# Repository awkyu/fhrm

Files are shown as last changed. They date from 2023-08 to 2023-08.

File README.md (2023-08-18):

# fhrm
BME 398: Fetal Heart Rate Monitor Circuit Design

This project was a small design project that was never fully realized as a proposal for an at-home Fetal Heart Rate Monitor. Signal artefacts are a major issue in current fetal heart rate sensors, leading to misdiagnoses that can lead to fetal mortality. Both Fetal Heart Rate and Fetal Movement are essential indicators for fetal health, providing information on cardiovascular and nervous system development, respectively. The device proposed here aims to limit these artefacts.

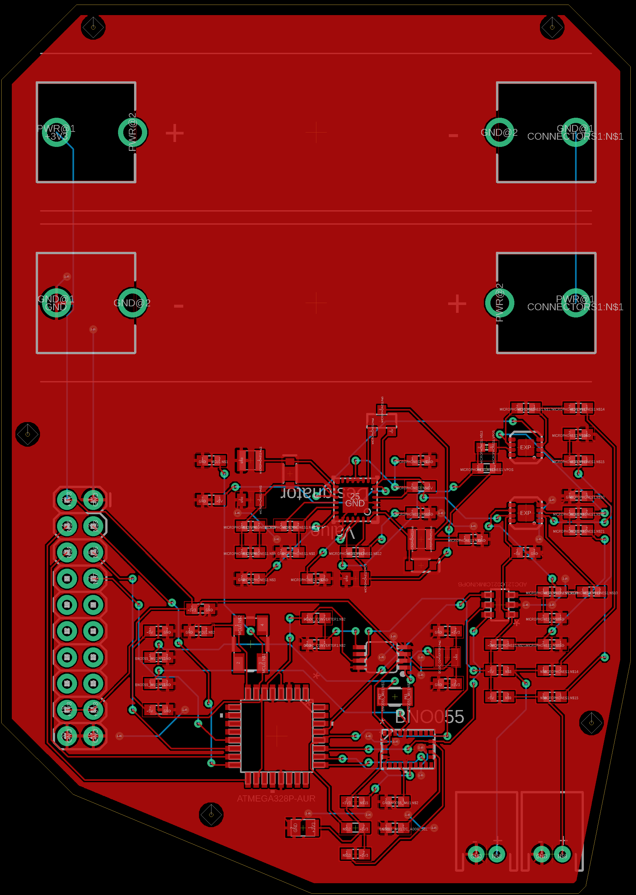
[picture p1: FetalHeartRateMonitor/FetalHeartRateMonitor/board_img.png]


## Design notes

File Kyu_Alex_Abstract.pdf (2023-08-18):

Abstract— Signal artefacts are a major issue in current fetal heart rate sensors, leading to misdiagnoses that can lead to fetal mortality. Both Fetal Heart Rate and Fetal Movement are essential indicators for fetal health, providing information on cardiovascular and nervous system development, respectively. The device proposed here aims to limit these artefacts.

Clinical Relevance— The design presented establishes an alternative device that would eliminate Maternal Heart Rate Artefact in Fetal Heart Rate measurements while providing additional movement information, reducing misinterpretation of signal output and misdiagnosis of abnormal fetal heart rates.

I. INTRODUCTION

In the perinatal period of pregnancy, both Fetal Heart Rate and Fetal Movement are major health indicators. Fetal movement has been shown to identify an infants’ neuro-motor development and brain dysfunction while Fetal Heart Rate indicative to fetal conditions that could lead to pre-existing fetal death [1, 2].

Currently, fetal heart rate is captured through cardiotocography, a method that uses ultrasound waves. When an abnormal heart rate is detected, a physician may decide to deliver the fetus early by performing a cesarean section. However, two artefacts may appear in these which could lead to a misdiagnosis. The first is the Maternal Heart Rate Artefact (MHRA) when the mother’s heart rate is misinterpreted by the CTG machine as the fetus’s and the second is the Fetal Heart Rate Artefact (FHRA) when a fetal heart rate is processed or outputted incorrectly—this can occur in the case of twins where one fetus’s heart rate can be interpreted as the others. A preliminary study identified these artefacts as part of 40% of perinatal fatalities examined in a sample report from 2009 to 2019 [1]. The device here provides a proposed way to measure fetal heart rate more accurately by eliminating these artefacts to decrease rates of perinatal mortality while also providing other fetal movement characteristics.

II. METHODS
The proposed sensor presented here is a dual microphone transducer to capture fetal heart rate with an IMU sensor to capture fetal movement. One microphone would be used to capture the heart rate of the fetus while the other microphone would be used to filter out ambient sounds and the maternal heart rate, using a differential operational amplifier topology. This would eliminate or reduce MHRA. This signal was then converted into a digital signal using a non-inverting level shifter. The IMU would be used to capture fetal movements, like other accelerometer-based fetal movement sensor systems. This system also includes a touchscreen for user interaction and to display relevant information related to the sensor readings.

III. RESULTS
The dual microphone schematic is shown below.

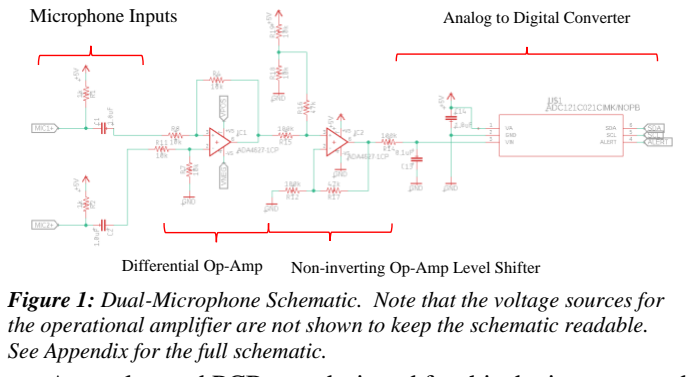
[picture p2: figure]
See Appendix for the full schematic.; Microphone Inputs; Differential Op-Amp; Analog to Digital Converter; Non-inverting Op-Amp Level Shifter

A two-layered PCB was designed for this device, powered by two AA batteries. All circuit components are on the top layer, except the ports that connect to the touchscreen which are on the bottom side. This eliminates the problem of the touchscreen inadvertently interacting with other components on the PCB. See Appendix for a figure of the PCB.

IV. DISCUSSION & CONCLUSION
It is worth noting that this is more of a proof of concept for a potential solution to some common problems that can occur with currently used cardiotocography devices while also providing additional fetal health informatics. However, additional filters, and methods should be investigated to
improve measurements. | For example, reinvestigating
ultrasound | transducers, | additional | microphones, | and
additional filtering methods may help further eliminate noise for fetal heart rate monitoring. And for fetal movement monitoring, other vibration-based sensors should be investigated like piezoelectric diaphragms and other acoustic sensors. These other sensors have been shown to be able to detect weaker movements, but also tend to generate higher power signal artefacts [2, 3].

Furthermore, board design should be analyzed to make sure that it is optimized for both noise reduction and for overall product design. Port placement, touchscreen placement, and battery placement should be reconsidered from a product perspective. Finally, other components should be analyzed to ensure that analog and digital signals are in their respective sections.

A. Kyu

## Proposed Wearable Fetal Heart Rate and Fetal Movement Sensor that Eliminates Maternal Heart Rate Artefact

Figure 1: Dual-Microphone Schematic. Note that the voltage sources for the operational amplifier are not shown to keep the schematic readable.

REFERENCES

[1] D. J. Kiely, L. W. Oppenheimer, and J. C. Dornan, “Unrecognized maternal heart rate artefact in cases of perinatal mortality reported to the United States Food and Drug Administration from 2009 to 2019: a critical patient safety issue,” BMC Pregnancy and Childbirth, vol. 19, no. 1, Dec. 2019, doi: 10.1186/s12884-019-2660-5.
[2] J. Lai et al., “Performance of a wearable acoustic system for fetal movement discrimination,” PLOS ONE, vol. 13, no. 5, p. e0195728, May 2018, doi: 10.1371/journal.pone.0195728.
[3] A. K. Ghosh et al., “A Novel Fetal Movement Simulator for the Performance Evaluation of Vibration Sensors for Wearable Fetal Movement Monitors,” Sensors, vol 20, no. 21, p. 6020, Oct 2020, doi:10.3390/s20216020

## Appendix

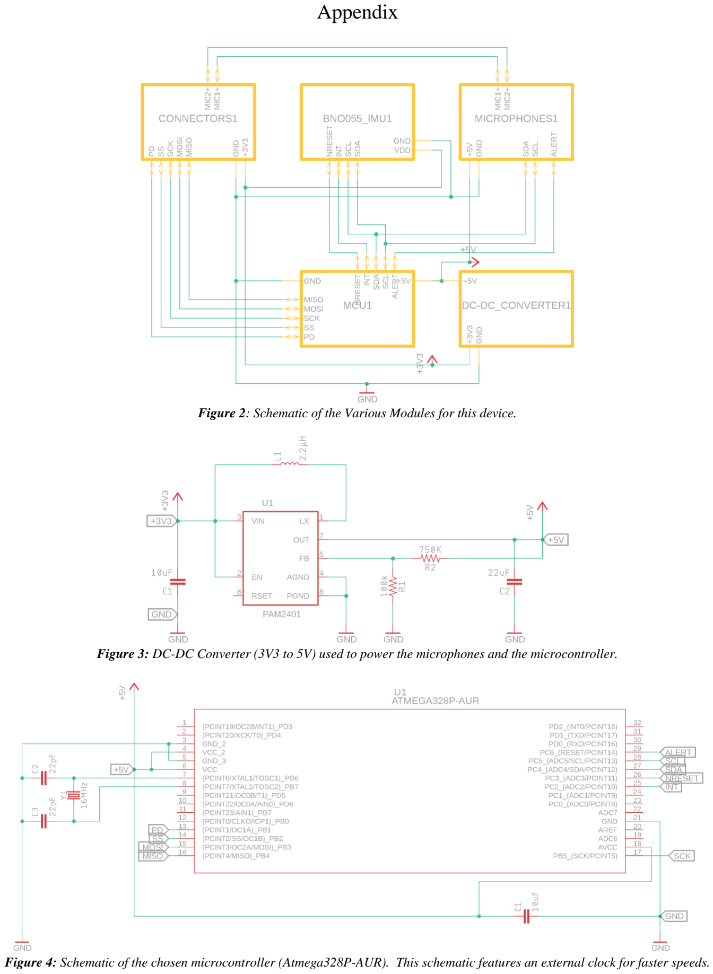
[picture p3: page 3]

Figure 2: Schematic of the Various Modules for this device.

Figure 3: DC-DC Converter (3V3 to 5V) used to power the microphones and the microcontroller.

Figure 4: Schematic of the chosen microcontroller (Atmega328P-AUR). This schematic features an external clock for faster speeds.

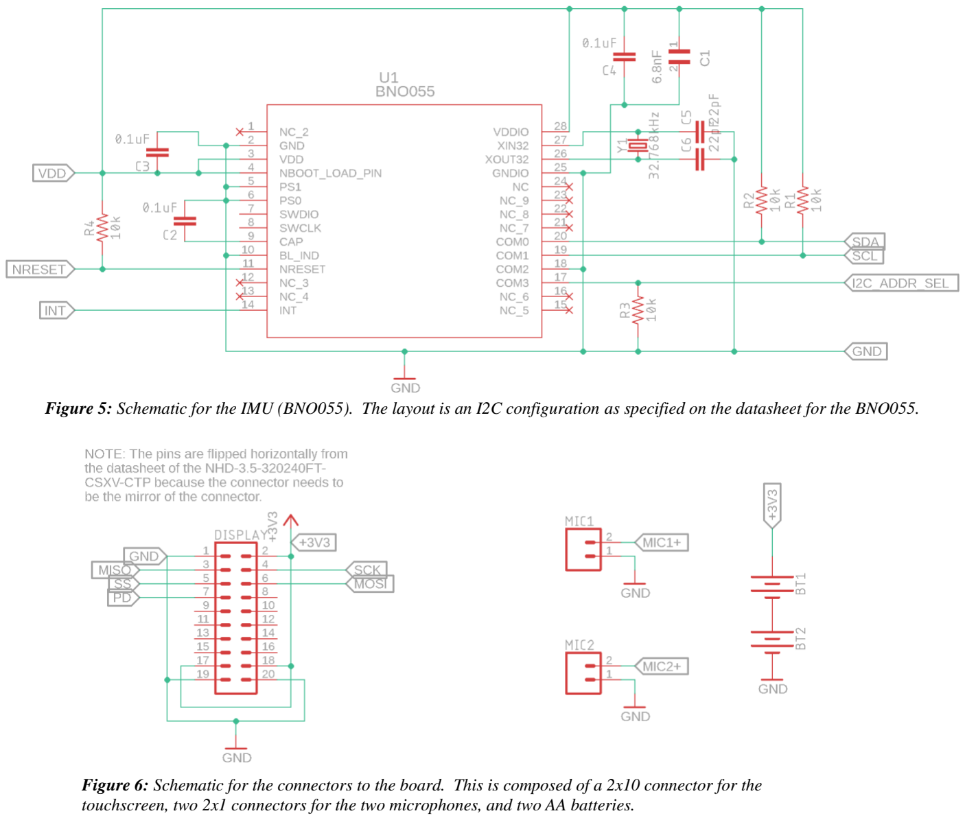
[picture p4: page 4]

Figure 5: Schematic for the IMU (BNO055). The layout is an I2C configuration as specified on the datasheet for the BNO055.

Figure 6: Schematic for the connectors to the board. This is composed of a 2x10 connector for the touchscreen, two 2x1 connectors for the two microphones, and two AA batteries.

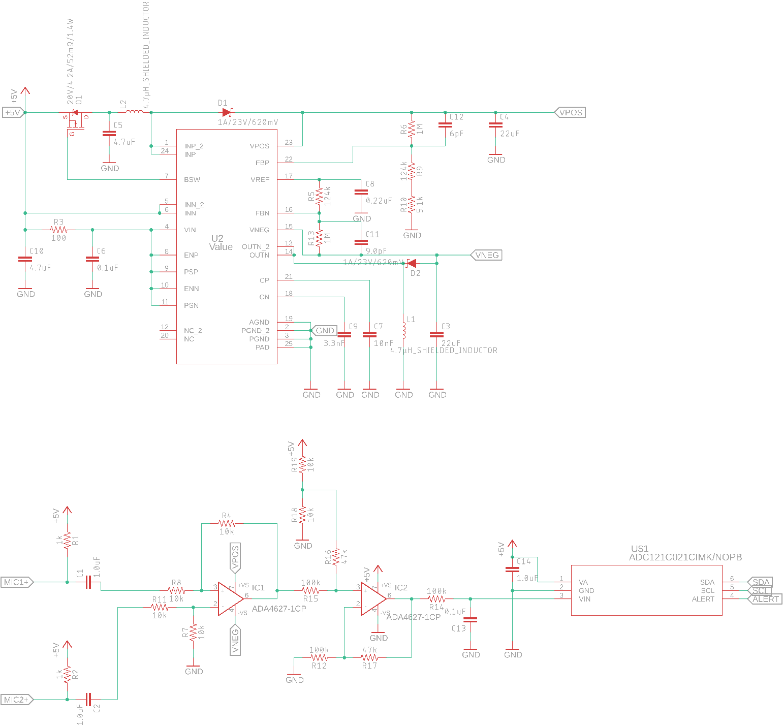
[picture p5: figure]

Figure 7: Schematic of the overall dual microphones system. The top half is to convert a 5V input to ~ +/-10V output that is then provided as the VPOS and VNEG to the differential operation amplifier topology. The bottom half is the one shown in the abstract above, which contains the inputs to the microphone, a differential op-amp topology, a non-inverting op-amp level shifter (to shift the negative voltage to 0V), and an analog-to-digital converter.

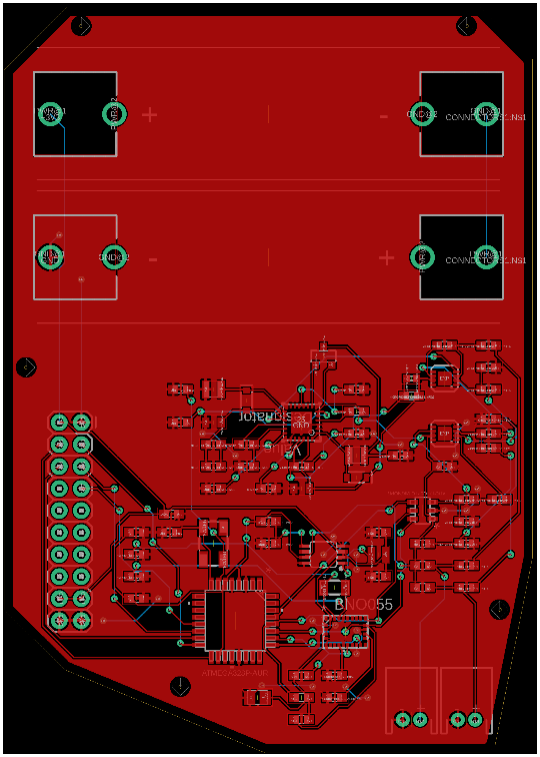
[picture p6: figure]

Figure 8: Board design for the proposed device. This is a 2-layer PCB with all components are on the top layer except the connectors for the touchscreen.

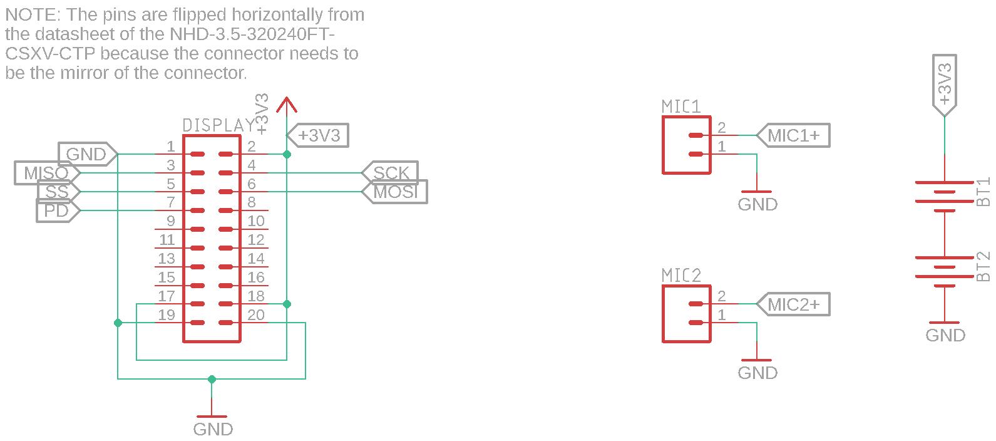
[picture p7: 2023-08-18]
FetalHeartRateMonitor/FetalHeartRateMonitor/conn_sch.png

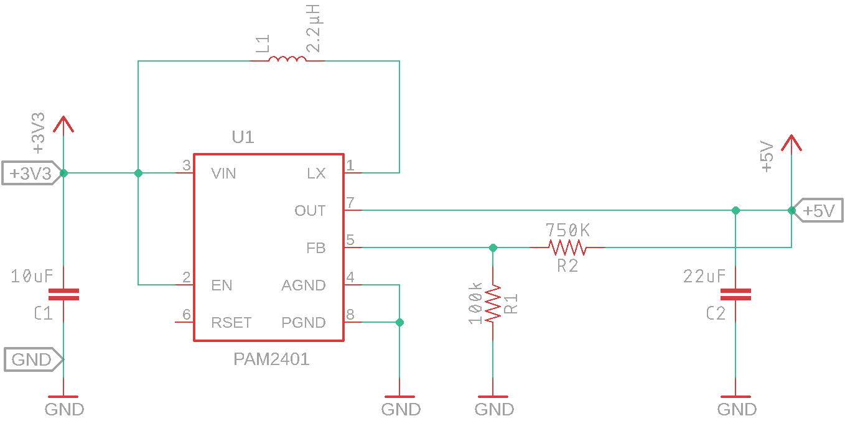
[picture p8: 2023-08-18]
FetalHeartRateMonitor/FetalHeartRateMonitor/dc-dc_conv_sch.png

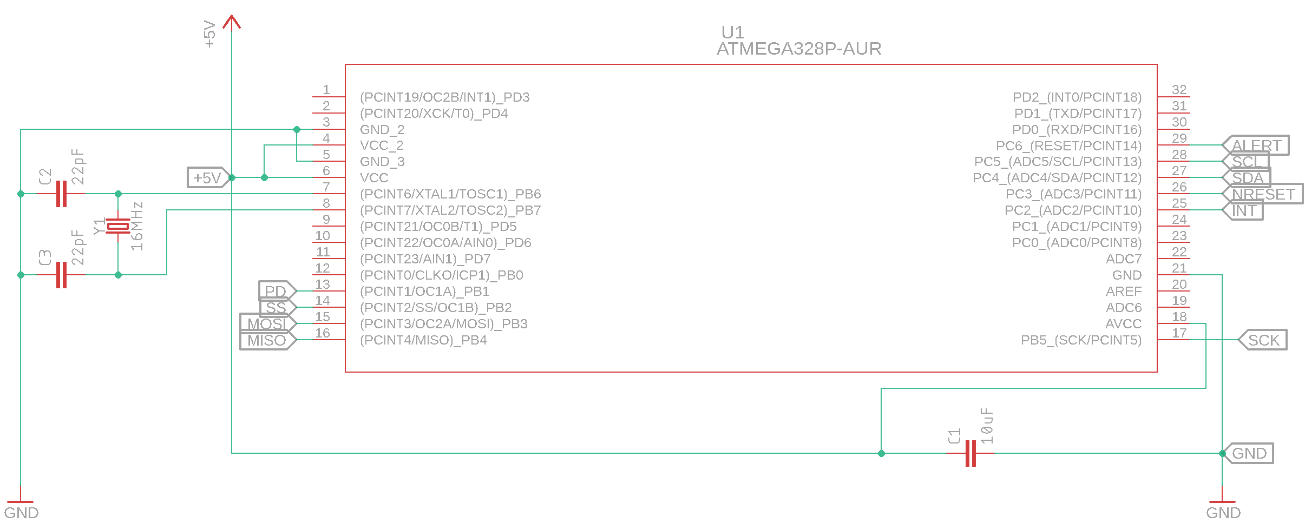
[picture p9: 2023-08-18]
FetalHeartRateMonitor/FetalHeartRateMonitor/mcu_sch.png

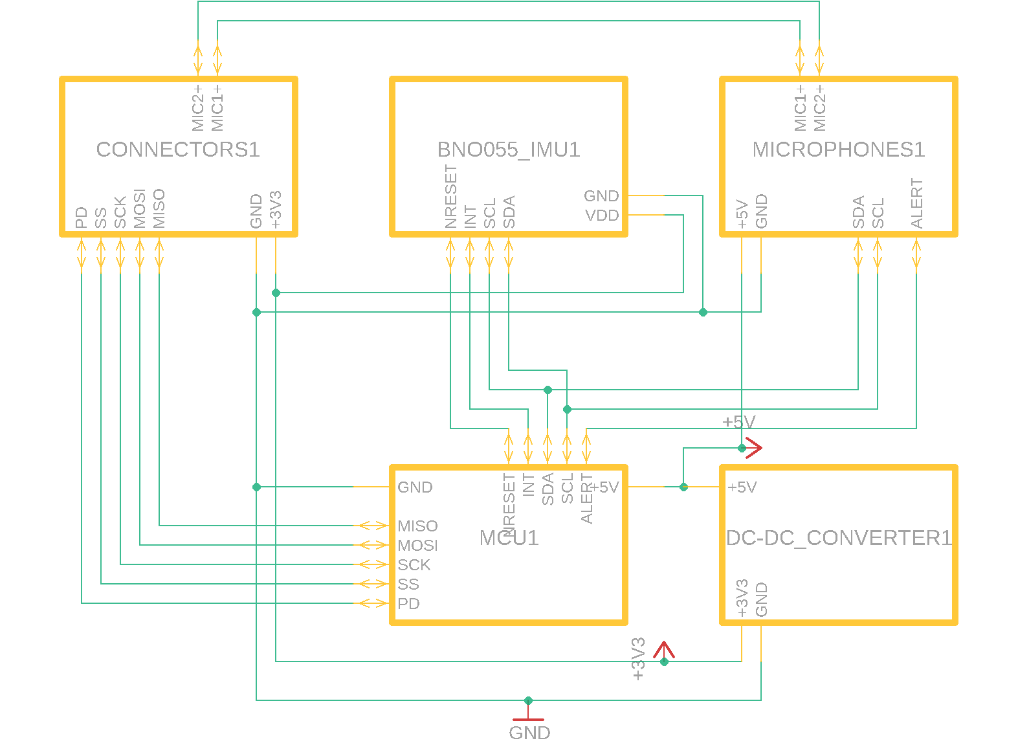
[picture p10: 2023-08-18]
FetalHeartRateMonitor/FetalHeartRateMonitor/mod_sch.png

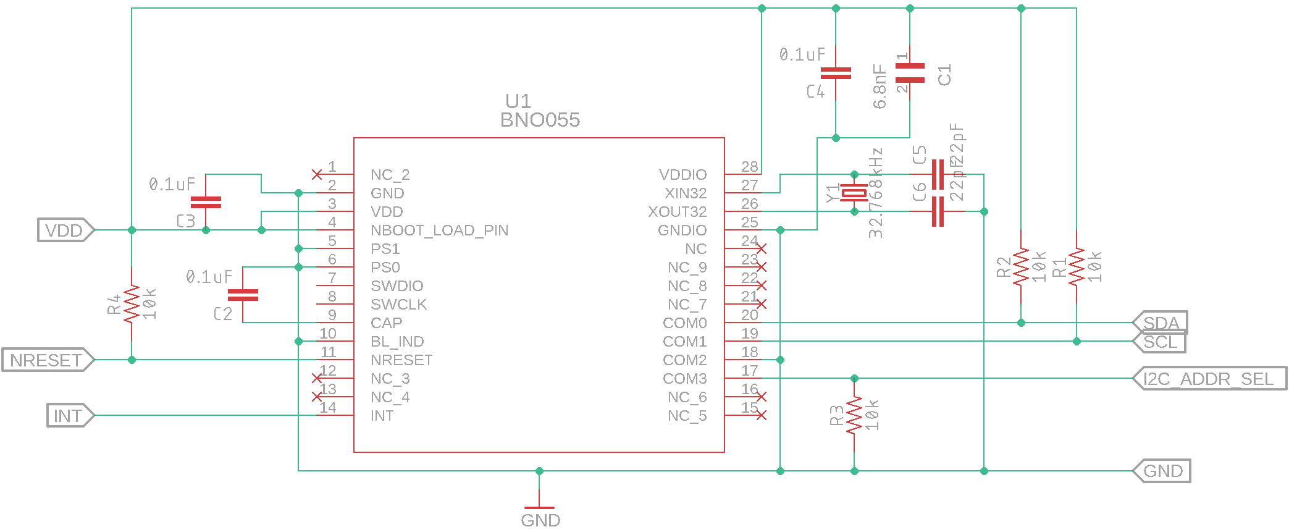
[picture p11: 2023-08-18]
FetalHeartRateMonitor/FetalHeartRateMonitor/imu_sch.png

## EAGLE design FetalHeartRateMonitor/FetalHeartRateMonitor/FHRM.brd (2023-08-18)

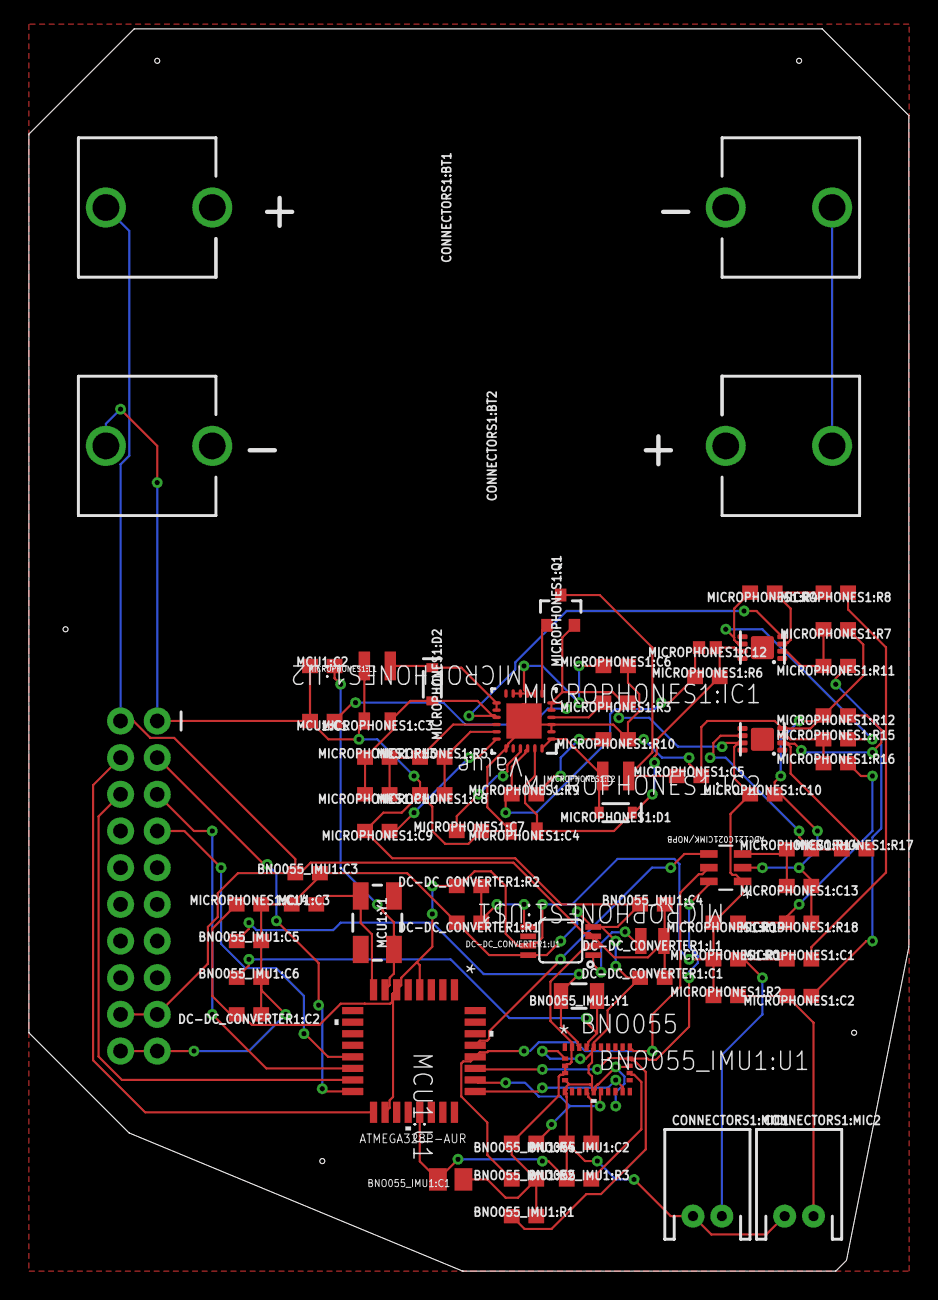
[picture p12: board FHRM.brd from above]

Board: 2 copper layers, 60.9 x 86.0 mm, 70 parts (1 on the bottom side), 47 nets.

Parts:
BNO055_IMU1:C1: 6.8nF; CAPC2012X140N
BNO055_IMU1:C2, BNO055_IMU1:C3, BNO055_IMU1:C4: 0.1uF; 0603
BNO055_IMU1:C5, BNO055_IMU1:C6: 22pF; 0603
BNO055_IMU1:R1, BNO055_IMU1:R2, BNO055_IMU1:R3, BNO055_IMU1:R4: 10k; 0603
BNO055_IMU1:U1: BNO055; QFN_BNO055_BOS
BNO055_IMU1:Y1: 32.768kHz; CRYSTAL-SMD-3.2X1.5MM
CONNECTORS1:BT1, CONNECTORS1:BT2: BATTERY-AA
CONNECTORS1:DISPLAY: 2X10
CONNECTORS1:MIC1, CONNECTORS1:MIC2: JST-2-PTH
DC-DC_CONVERTER1:C1: 10uF; 0603
DC-DC_CONVERTER1:C2: 22uF; 0603
DC-DC_CONVERTER1:L1: 2.2μH; 0805-WIDE
DC-DC_CONVERTER1:R1: 100k; 0603
DC-DC_CONVERTER1:R2: 750K; 0603
DC-DC_CONVERTER1:U1: PAM2401; MSOP8
MCU1:C1: 10uF; 0603
MCU1:C2, MCU1:C3: 22pF; 0603
MCU1:U1: ATMEGA328P-AUR; 32A_ATM
MCU1:Y1: 16MHz; CRYSTAL-SMD-5X3.2-4PAD
MICROPHONES1:C1, MICROPHONES1:C2, MICROPHONES1:C14: 1.0uF; 0603
MICROPHONES1:C3, MICROPHONES1:C4: 22uF; 0805
MICROPHONES1:C5, MICROPHONES1:C10: 4.7uF; 0603
MICROPHONES1:C6, MICROPHONES1:C13: 0.1uF; 0603
MICROPHONES1:C7: 10nF; 0603
MICROPHONES1:C8: 0.22uF; 0603
MICROPHONES1:C9: 3.3nF; 0603
MICROPHONES1:C11: 9.0pF; 0603
MICROPHONES1:C12: 6pF; 0402
MICROPHONES1:D1, MICROPHONES1:D2: 1A/23V/620mV; SOD-323
MICROPHONES1:IC1, MICROPHONES1:IC2: ADA4627-1CP; LFCSP8
MICROPHONES1:L1, MICROPHONES1:L2: 4.7μH_SHIELDED_INDUCTOR; 1008(2520)
MICROPHONES1:Q1: 20V/4.2A/52mΩ/1.4W; SOT23-3
MICROPHONES1:R1, MICROPHONES1:R2: 1k; 0603
MICROPHONES1:R3: 100; 0603
MICROPHONES1:R4, MICROPHONES1:R7, MICROPHONES1:R8, MICROPHONES1:R11, MICROPHONES1:R18, MICROPHONES1:R19: 10k; 0603
MICROPHONES1:R5, MICROPHONES1:R9: 124k; 0603
MICROPHONES1:R6, MICROPHONES1:R13: 1M; 0603
MICROPHONES1:R10: 5.1k; 0603
MICROPHONES1:R12, MICROPHONES1:R14, MICROPHONES1:R15: 100k; 0603
MICROPHONES1:R16, MICROPHONES1:R17: 47k; 0603
MICROPHONES1:U2: Value; RGE0024B
MICROPHONES1:U$1: ADC121C021CIMK/NOPB; MK06A

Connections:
+3V3: BNO055_IMU1:C1.1, BNO055_IMU1:C3.1, BNO055_IMU1:C4.2, BNO055_IMU1:R1.2, BNO055_IMU1:R2.2, BNO055_IMU1:R4.2, BNO055_IMU1:U1.3, BNO055_IMU1:U1.4, BNO055_IMU1:U1.28, CONNECTORS1:BT1.PWR@1, CONNECTORS1:DISPLAY.2, CONNECTORS1:DISPLAY.17, CONNECTORS1:DISPLAY.18, DC-DC_CONVERTER1:C1.2, DC-DC_CONVERTER1:L1.1, DC-DC_CONVERTER1:U1.2, DC-DC_CONVERTER1:U1.3
+5V: DC-DC_CONVERTER1:C2.2, DC-DC_CONVERTER1:R2.1, DC-DC_CONVERTER1:U1.7, MCU1:C1.1, MCU1:U1.4, MCU1:U1.6, MCU1:U1.18, MICROPHONES1:C10.1, MICROPHONES1:C14.1, MICROPHONES1:IC2.7, MICROPHONES1:Q1.2, MICROPHONES1:R1.1, MICROPHONES1:R2.1, MICROPHONES1:R3.1, MICROPHONES1:R19.2, MICROPHONES1:U2.5, MICROPHONES1:U2.6, MICROPHONES1:U$1.1
BNO055_IMU1:I2C_ADDR_SEL: BNO055_IMU1:R3.2, BNO055_IMU1:U1.17
BNO055_IMU1:N$1: BNO055_IMU1:C5.1, BNO055_IMU1:U1.27, BNO055_IMU1:Y1.P$2
BNO055_IMU1:N$2: BNO055_IMU1:C2.1, BNO055_IMU1:U1.9
BNO055_IMU1:N$3: BNO055_IMU1:C6.1, BNO055_IMU1:U1.26, BNO055_IMU1:Y1.P$1
CONNECTORS1:N$1: CONNECTORS1:BT1.GND@1, CONNECTORS1:BT2.PWR@1
DC-DC_CONVERTER1:N$1: DC-DC_CONVERTER1:L1.2, DC-DC_CONVERTER1:U1.1
DC-DC_CONVERTER1:N$2: DC-DC_CONVERTER1:R1.1, DC-DC_CONVERTER1:R2.2, DC-DC_CONVERTER1:U1.5
GND: BNO055_IMU1:C1.2, BNO055_IMU1:C2.2, BNO055_IMU1:C3.2, BNO055_IMU1:C4.1, BNO055_IMU1:C5.2, BNO055_IMU1:C6.2, BNO055_IMU1:R3.1, BNO055_IMU1:U1.2, BNO055_IMU1:U1.5, BNO055_IMU1:U1.6, BNO055_IMU1:U1.10, BNO055_IMU1:U1.18, BNO055_IMU1:U1.25, CONNECTORS1:BT2.GND@1, CONNECTORS1:DISPLAY.1, CONNECTORS1:DISPLAY.19, CONNECTORS1:DISPLAY.20, CONNECTORS1:MIC1.1, CONNECTORS1:MIC2.1, DC-DC_CONVERTER1:C1.1, DC-DC_CONVERTER1:C2.1, DC-DC_CONVERTER1:R1.2, DC-DC_CONVERTER1:U1.4, DC-DC_CONVERTER1:U1.8, MCU1:C1.2, MCU1:C2.1, MCU1:C3.1, MCU1:U1.3, MCU1:U1.5, MCU1:U1.21, MICROPHONES1:C3.2, MICROPHONES1:C4.2, MICROPHONES1:C5.2, MICROPHONES1:C6.2, MICROPHONES1:C7.2, MICROPHONES1:C8.2, MICROPHONES1:C9.2, MICROPHONES1:C10.2, MICROPHONES1:C13.1, MICROPHONES1:C14.2, MICROPHONES1:IC2.4, MICROPHONES1:L1.2, MICROPHONES1:R7.1, MICROPHONES1:R10.1, MICROPHONES1:R12.2, MICROPHONES1:R18.1, MICROPHONES1:U2.2, MICROPHONES1:U2.3, MICROPHONES1:U2.19, MICROPHONES1:U2.25, MICROPHONES1:U$1.2
MCU1:N$1: MCU1:C2.2, MCU1:U1.7, MCU1:Y1.3
MCU1:N$2: MCU1:C3.2, MCU1:U1.8, MCU1:Y1.1
MICROPHONES1:N$1: MICROPHONES1:C6.1, MICROPHONES1:R3.2, MICROPHONES1:U2.4, MICROPHONES1:U2.8, MICROPHONES1:U2.9, MICROPHONES1:U2.10, MICROPHONES1:U2.11
MICROPHONES1:N$2: MICROPHONES1:C7.1, MICROPHONES1:U2.21
MICROPHONES1:N$3: MICROPHONES1:C9.1, MICROPHONES1:U2.18
MICROPHONES1:N$4: MICROPHONES1:Q1.1, MICROPHONES1:U2.7
MICROPHONES1:N$5: MICROPHONES1:C5.1, MICROPHONES1:L2.1, MICROPHONES1:Q1.3
MICROPHONES1:N$6: MICROPHONES1:D1.A, MICROPHONES1:L2.2, MICROPHONES1:U2.1, MICROPHONES1:U2.24
MICROPHONES1:N$7: MICROPHONES1:IC2.3, MICROPHONES1:R15.1, MICROPHONES1:R16.1
MICROPHONES1:N$8: MICROPHONES1:C8.1, MICROPHONES1:R5.2, MICROPHONES1:U2.17
MICROPHONES1:N$9: MICROPHONES1:C11.1, MICROPHONES1:R5.1, MICROPHONES1:R13.2, MICROPHONES1:U2.16
MICROPHONES1:N$10: MICROPHONES1:IC2.2, MICROPHONES1:R12.1, MICROPHONES1:R17.2
MICROPHONES1:N$11: MICROPHONES1:D2.C, MICROPHONES1:L1.1, MICROPHONES1:U2.13, MICROPHONES1:U2.14
MICROPHONES1:N$12: MICROPHONES1:R9.2, MICROPHONES1:R10.2
MICROPHONES1:N$13: MICROPHONES1:C12.2, MICROPHONES1:R6.1, MICROPHONES1:R9.1, MICROPHONES1:U2.22
MICROPHONES1:N$14: MICROPHONES1:C1.2, MICROPHONES1:R8.1
MICROPHONES1:N$15: MICROPHONES1:C2.1, MICROPHONES1:R11.1
MICROPHONES1:N$16: MICROPHONES1:IC1.2, MICROPHONES1:R7.2, MICROPHONES1:R11.2
MICROPHONES1:N$17: MICROPHONES1:IC1.3, MICROPHONES1:R4.1, MICROPHONES1:R8.2
MICROPHONES1:N$18: MICROPHONES1:IC1.6, MICROPHONES1:R4.2, MICROPHONES1:R15.2
MICROPHONES1:N$19: MICROPHONES1:IC2.6, MICROPHONES1:R14.2, MICROPHONES1:R17.1
MICROPHONES1:N$20: MICROPHONES1:C13.2, MICROPHONES1:R14.1, MICROPHONES1:U$1.3
MICROPHONES1:N$21: MICROPHONES1:R16.2, MICROPHONES1:R18.2, MICROPHONES1:R19.1
MICROPHONES1:VNEG: MICROPHONES1:C3.1, MICROPHONES1:C11.2, MICROPHONES1:D2.A, MICROPHONES1:IC1.4, MICROPHONES1:R13.1, MICROPHONES1:U2.15
MICROPHONES1:VPOS: MICROPHONES1:C4.1, MICROPHONES1:C12.1, MICROPHONES1:D1.C, MICROPHONES1:IC1.7, MICROPHONES1:R6.2, MICROPHONES1:U2.23
unnamed: CONNECTORS1:DISPLAY.3, MCU1:U1.16
unnamed: CONNECTORS1:DISPLAY.6, MCU1:U1.15
unnamed: CONNECTORS1:DISPLAY.4, MCU1:U1.17
unnamed: CONNECTORS1:DISPLAY.5, MCU1:U1.14
unnamed: CONNECTORS1:DISPLAY.7, MCU1:U1.13
unnamed: CONNECTORS1:MIC1.2, MICROPHONES1:C1.1, MICROPHONES1:R1.2
unnamed: CONNECTORS1:MIC2.2, MICROPHONES1:C2.2, MICROPHONES1:R2.2
unnamed: MCU1:U1.29, MICROPHONES1:U$1.4
unnamed: BNO055_IMU1:R2.1, BNO055_IMU1:U1.20, MCU1:U1.28, MICROPHONES1:U$1.5
unnamed: BNO055_IMU1:R1.1, BNO055_IMU1:U1.19, MCU1:U1.27, MICROPHONES1:U$1.6
unnamed: BNO055_IMU1:U1.14, MCU1:U1.25
unnamed: BNO055_IMU1:R4.1, BNO055_IMU1:U1.11, MCU1:U1.26

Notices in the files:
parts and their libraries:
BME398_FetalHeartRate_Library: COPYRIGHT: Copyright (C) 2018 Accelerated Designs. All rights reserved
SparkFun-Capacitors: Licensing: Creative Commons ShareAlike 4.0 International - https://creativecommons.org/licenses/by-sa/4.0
